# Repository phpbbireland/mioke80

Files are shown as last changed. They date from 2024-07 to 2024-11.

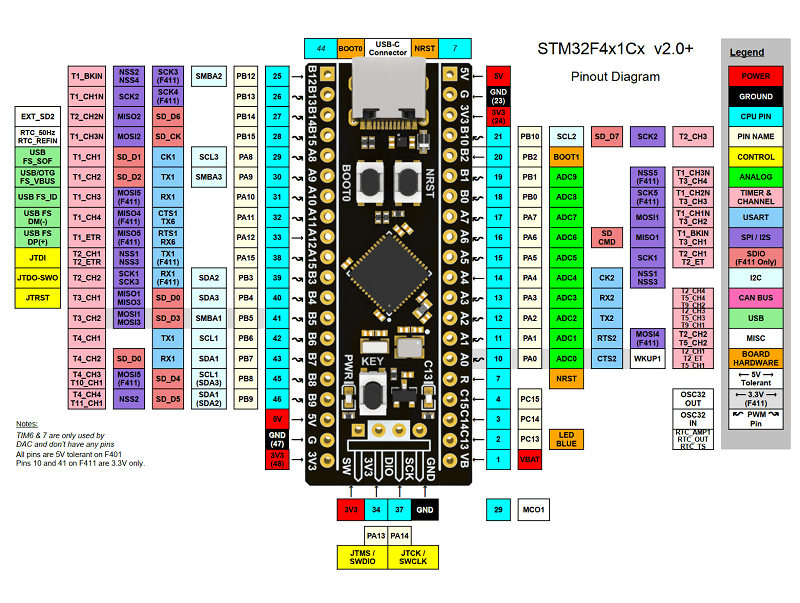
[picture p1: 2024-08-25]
blackpill_version/kicad/Pinout-Diagram.png

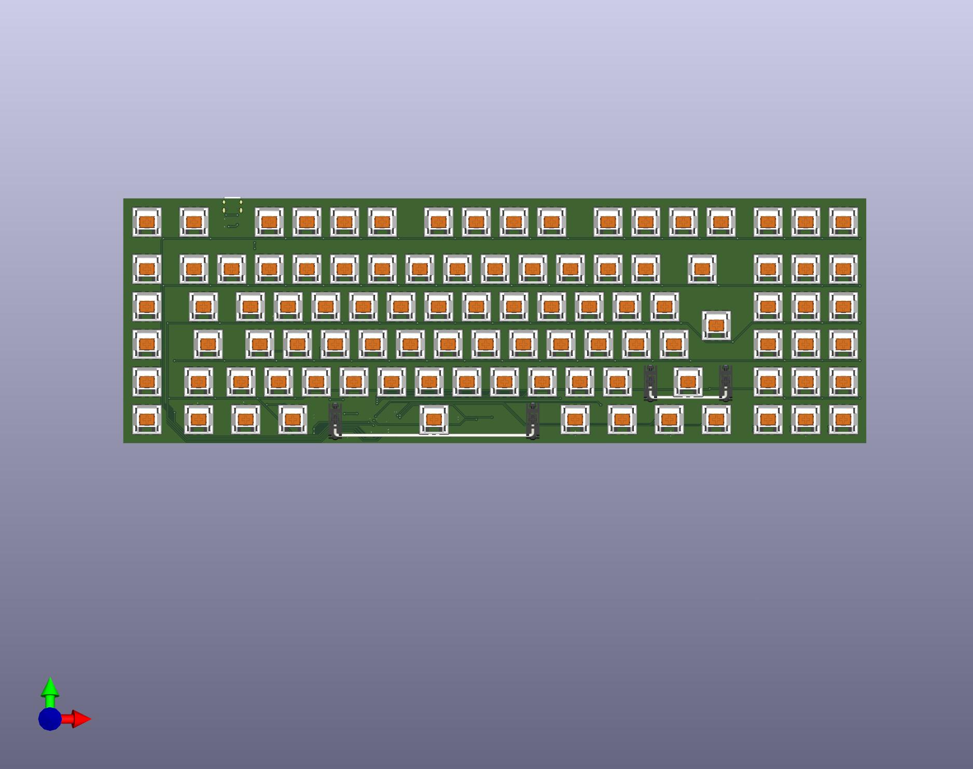
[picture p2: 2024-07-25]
images/Mioke80_front.jpg

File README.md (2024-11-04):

# Moving this repo to phpbbireland/mioke  
The new repo wil correct directory structure for this project... this repo will be deleted...

# mioke80 / ayla_411
QMK Based Open Hardware Keyboard with 99 Keys and Via Support

Just another open source / open hardware ~80% keyboard...

Ref: https://hackaday.io/project/197065-mioke80-iso-99-key-80-keyboard

+ Schematic complete...  
+ Software 80% complete...  
+ QMK/VIA code tested on Blackpill 411 Dev Board (see blackpill_version)... working 11th August 2024
+ Keyboard works... Now loads in usevia.app... Needed work to get RGB and Encoder working...

My main test code is now in /blackpill_version/QMK/ayla/ayla80  

I have designed a new test board using the STM32F411RETx, it contains all the necessary keyboard electronics (except for the key switches, matrix diodes and RGB leds as these are on
the actual keyboard PCB from the first prototype). Connection between boards is via 30 pin 1.27" pitch header connector.  

Note: *kicad2* folder contains working test copy, files will be moved to **kicad** once testing complete...  

Kicad Resources:  
[https://github.com/ebastler/marbastlib](https://github.com/ebastler/marbastlib)  
[https://github.com/joe-scotto/scottokeebs](https://github.com/joe-scotto/scottokeebs)

Matrix 10X10
```
    ┌───┐   ┌───┐┌───┐┌───┬───┬───┬───┐┌───┬───┬───┬───┐┌───┬───┬───┬───┐┌───┐┌───┐┌───┐
    │0,0│   │0,1││N/A││0,2│0,3│0,4│0,5││0,6│0,7│0,8│0,9││1,0│1,1│1,2│1,3││1,4││1,5││1,6│
    └───┘   └───┘└───┘└───┴───┴───┴───┘└───┴───┴───┴───┘└───┴───┴───┴───┘└───┘└───┘└───┘
    ┌───┐   ┌───┬───┬───┬───┬───┬───┬───┬───┬───┬───┬───┬───┬───┬───────┐┌───┐┌───┐┌───┐
    │1,7│   │1,8│1,9│2,0│2,1│2,2│2,3│2,4│2,5│2,6│2,7│2,8│2,9│3,0│  3,1  ││3,2││3,3││3,4│
    ├───┤   ├───┴─┬─┴─┬─┴─┬─┴─┬─┴─┬─┴─┬─┴─┬─┴─┬─┴─┬─┴─┬─┴─┬─┴─┬─┴─┬─────┤├───┤├───┤├───┤
    │3,5│   │ 3,6 │3,7│3,8│3,9│4,0│4,1│4,2│4,3│4,4│4,5│4,6│4,7│4,8│     ││4,9││5,0││5,1│
    ├───┤   ├─────┴┬──┴┬──┴┬──┴┬──┴┬──┴┬──┴┬──┴┬──┴┬──┴┬──┴┬──┴┬──┴┐    │├───┤├───┤├───┤
    │5,2│   │ 5,3  │5,4│5,5│5,6│5,7│5,8│5,9│6,0│6,1│6,2│6,3│6,4│6,5│6.6 ││6,7││6,8││6,9│
    ├───┤   ├────┬─┴─┬─┴─┬─┴─┬─┴─┬─┴─┬─┴─┬─┴─┬─┴─┬─┴─┬─┴─┬─┴─┬─┴───┴────┤├───┤├───┤├───┤
    │7,0│   │7,1 │7,2│7,3│7,4│7,5│7,6│7,7│7,8│7,9│8,0│8,1│8,2│    8,3   ││8,4││8,5││8,6│
    ├───┤   ├────┼───┴┬──┴─┬─┴───┴───┴───┴───┴───┴──┬┴───┼───┴┬────┬────┤├───┤├───┤├───┤
    │8,7│   │8.8 │8,9 │9,1 │           9,2          │9,3 │9,4 │9,5 │9,6 ││9,7││9,8││9,9│
    └───┘   └────┴────┴────┴────────────────────────┴────┴────┴────┴────┘└───┘└───┘└───┘
```

Will add 4x3 number keypad and rotary encoder which attaches via a 5x2 ribbon cable but might need more gpio pin, another process for this version?
The Blackpill version has an endoder... 
**Note**
Some GPIO pins may change as it appears some can't be used (according to sources)...

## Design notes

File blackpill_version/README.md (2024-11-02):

# mioke80 / ayla_411 / BlackPill Version

QMK Based Open Hardware Keyboard with 99 Keys + Rotary Encoder
Just another open source / open hardware ~80% keyboard...

Ref: https://hackaday.io/project/197065-mioke80-iso-99-key-80-keyboard

The new 10x10 matrix version requires only 20 GPIO pins, previously the 18x6 required 24. As it turns out, when taking into account pins that can't be used, and those, that are not recommended to use, we did not have enough GPIOs with old 19x6 matrix if we needed macros (flash), hence the 10x10 matrix update...

Schematic complete (10x10 matrix version)...  
Software 75% complete (no macros yet)...  

The original 18x6 matrix code was tested on Blackpill 411 Dev Board... working 11th August 2024  

The QMK folder for reference only, it's my local copy for building (not part of the main qmk_firmware repository).
Perhaps some day, if I get this complete...  

**Status**
+ Designed a prototype PCB using an STM32 411 Blackpill for testing... ***complete***
+ Test prototype PCB and initial keyboard code... ***complete, 100% working***
+ Now loads in usevia.app ***(I removed unnecessary files... RGB and Encoder require lots more work)***
+ Write and test RGB code... ***in progress***
+ I will proceed to a fully assembled PCB using the STM32F072CBT6 and associated components.

The keyboard code was simple enough but RGB code looks a little more involved...  
  
**Col/Row**
```
    ┌───┐   ┌───┐┌───┐┌───┬───┬───┬───┐┌───┬───┬───┬───┐┌───┬───┬───┬───┐┌───┐┌───┐┌───┐
    │0,0│   │0,1││N/A││0,2│0,3│0,4│0,5││0,6│0,7│0,8│0,9││1,0│1,1│1,2│1,3││1,4││1,5││1,6│
    └───┘   └───┘└───┘└───┴───┴───┴───┘└───┴───┴───┴───┘└───┴───┴───┴───┘└───┘└───┘└───┘
    ┌───┐   ┌───┬───┬───┬───┬───┬───┬───┬───┬───┬───┬───┬───┬───┬───────┐┌───┐┌───┐┌───┐
    │1,7│   │1,8│1,9│2,0│2,1│2,2│2,3│2,4│2,5│2,6│2,7│2,8│2,9│3,0│  3,1  ││3,2││3,3││3,4│
    ├───┤   ├───┴─┬─┴─┬─┴─┬─┴─┬─┴─┬─┴─┬─┴─┬─┴─┬─┴─┬─┴─┬─┴─┬─┴─┬─┴─┬─────┤├───┤├───┤├───┤
    │3,5│   │ 3,6 │3,7│3,8│3,9│4,0│4,1│4,2│4,3│4,4│4,5│4,6│4,7│4,8│     ││4,9││5,0││5,1│
    ├───┤   ├─────┴┬──┴┬──┴┬──┴┬──┴┬──┴┬──┴┬──┴┬──┴┬──┴┬──┴┬──┴┬──┴┐    │├───┤├───┤├───┤
    │5,2│   │ 5,3  │5,4│5,5│5,6│5,7│5,8│5,9│6,0│6,1│6,2│6,3│6,4│6,5│6.6 ││6,7││6,8││6,9│
    ├───┤   ├──────┴┬──┴┬──┴┬──┴┬──┴┬──┴┬──┴┬──┴┬──┴┬──┴┬──┴┬──┴┬──┴────┤├───┤├───┤├───┤
    │7,0│   │  7,1  │7,2│7,3│7,4│7,5│7,6│7,7│7,8│7,9│8,0│8,1│8,2│  8,3  ││8,4││8,5││8,6│
    ├───┤   ├────┬──┴─┬─┴──┬┴───┴───┴───┴───┴───┴───┴───┴┬──┴─┬─┴──┬────┤├───┤├───┤├───┤
    │8,7│   │8.8 │8,9 │9,1 │           9,2          │9,3 │9,4 │9,5 │9,6 ││9,7││9,8││9,9│
    └───┘   └────┴────┴────┴────────────────────────┴────┴────┴────┴────┘└───┘└───┘└───┘
```
**Matrix**
```
       C0    C1    C2    C3    C4    C5    C6    C7    C8    C9
      ┌───┐ ┌───┐ ┌───┐ ┌───┐ ┌───┐ ┌───┐ ┌───┐ ┌───┐ ┌───┐ ┌───┐
R0    │Rst│ │Esc│ │F1 │ │F2 │ │F3 │ │F4 │ │F5 │ │F6 │ │F7 │ │F8 │
      └───┘ └───┘ └───┘ └───┘ └───┘ └───┘ └───┘ └───┘ └───┘ └───┘
      ┌───┐ ┌───┐ ┌───┐ ┌───┐ ┌───┐ ┌───┐ ┌───┐ ┌───┐ ┌───┐ ┌───┐
R1    │F9 │ │F10│ │F11│ │F12│ │Prl│ │SL │ │Pse│ │M1 │ │ ` │ │ 1 │
      └───┘ └───┘ └───┘ └───┘ └───┘ └───┘ └───┘ └───┘ └───┘ └───┘
      ┌───┐ ┌───┐ ┌───┐ ┌───┐ ┌───┐ ┌───┐ ┌───┐ ┌───┐ ┌───┐ ┌───┐
R2    │ 2 │ │ 3 │ │ 4 │ │ 5 │ │ 6 │ │ 7 │ │ 8 │ │ 9 │ │ 0 │ │ - │
      └───┘ └───┘ └───┘ └───┘ └───┘ └───┘ └───┘ └───┘ └───┘ └───┘
      ┌───┐ ┌───┐ ┌───┐ ┌───┐ ┌───┐ ┌───┐ ┌───┐ ┌───┐ ┌───┐ ┌───┐
R3    │ + │ │BS │ │Ins│ │Hme│ │PgU│ │M2 │ │Tab│ │ Q │ │ W │ │ E │
      └───┘ └───┘ └───┘ └───┘ └───┘ └───┘ └───┘ └───┘ └───┘ └───┘
      ┌───┐ ┌───┐ ┌───┐ ┌───┐ ┌───┐ ┌───┐ ┌───┐ ┌───┐ ┌───┐ ┌───┐
R4    │ R │ │ T │ │ Y │ │ U │ │ I │ │ O │ │ P │ │ [ │ │ ] │ │ # │
      └───┘ └───┘ └───┘ └───┘ └───┘ └───┘ └───┘ └───┘ └───┘ └───┘
      ┌───┐ ┌───┐ ┌───┐ ┌───┐ ┌───┐ ┌───┐ ┌───┐ ┌───┐ ┌───┐ ┌───┐
R5    │Del│ │End│ │PgD│ │M3 │ │Cap│ │ A │ │ S │ │ D │ │ F │ │ G │
      └───┘ └───┘ └───┘ └───┘ └───┘ └───┘ └───┘ └───┘ └───┘ └───┘
      ┌───┐ ┌───┐ ┌───┐ ┌───┐ ┌───┐ ┌───┐ ┌───┐ ┌───┐ ┌───┐ ┌───┐
R6    │ H │ │ J │ │ K │ │ L │ │ ; │ │ @ │ │C R│ │<< │ │ > │ │ >>│
      └───┘ └───┘ └───┘ └───┘ └───┘ └───┘ └───┘ └───┘ └───┘ └───┘
      ┌───┐ ┌───┐ ┌───┐ ┌───┐ ┌───┐ ┌───┐ ┌───┐ ┌───┐ ┌───┐ ┌───┐
R7    │M4 │ │LSh│ │ Z │ │ X │ │ C │ │ V │ │ B │ │ N │ │ M │ │ , │
      └───┘ └───┘ └───┘ └───┘ └───┘ └───┘ └───┘ └───┘ └───┘ └───┘
      ┌───┐ ┌───┐ ┌───┐ ┌───┐ ┌───┐ ┌───┐ ┌───┐ ┌───┐ ┌───┐ ┌───┐
R8    │ . │ │ / │ │ \ │ │Rsh│ │M5 │ │ ↑ │ │M6 │ │M7 │ │Lcr│ │GUI│
      └───┘ └───┘ └───┘ └───┘ └───┘ └───┘ └───┘ └───┘ └───┘ └───┘
      ┌───┐ ┌───┐ ┌───┐ ┌───┐ ┌───┐ ┌───┐ ┌───┐ ┌───┐ ┌───┐ ┌───┐
R9    │Llt│ │S P│ │Rlt│ │Fn │ │Men│ │Rcr│ │ ← │ │ ↓ │ │ → │ │SPA│
      └───┘ └───┘ └───┘ └───┘ └───┘ └───┘ └───┘ └───┘ └───┘ └───┘
```

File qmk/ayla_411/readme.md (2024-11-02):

# ayla_411

ayla_411

*A short description of the keyboard/project*

* Keyboard Maintainer: [Mike](https://github.com/phpbbireland)
* Hardware Supported: *The PCBs, controllers supported*
* Hardware Availability: *Links to where you can find this hardware*

Make example for this keyboard (after setting up your build environment):

    make ayla_411:default
    make ayla/ayla80:via

Flashing example for this keyboard:

    make ayla_411:default:flash ?
    qmk flash ayla_ayla80_via.bin -km via

See the [build environment setup](https://docs.qmk.fm/#/getting_started_build_tools) and the [make instructions](https://docs.qmk.fm/#/getting_started_make_guide) for more information. Brand new to QMK? Start with our [Complete Newbs Guide](https://docs.qmk.fm/#/newbs).

## Bootloader

Enter the bootloader in 3 ways:

* **Bootmagic reset**: Hold down the key at (0,0) in the matrix (usually the top left key or Escape) and plug in the keyboard
* **Physical reset button**: Briefly press the button on the back of the PCB - some may have pads you must short instead
* **Keycode in layout**: Press the key mapped to `QK_BOOT` if it is available

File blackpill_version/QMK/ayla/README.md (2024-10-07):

# ayla keyboards

ayla

*A short description of the keyboard/project*

* Keyboard Maintainer: [Mike](https://github.com/phpbbireland)
* Hardware Supported: [Hackaday](https://hackaday.io/project/197065-mioke80-iso-ansi-99-key-80-keyboard)
* Hardware Availability: *Once complete and 100% working, I will supply Links to where you can find this hardware*

This keyboard is similar to others in QMK keyboard directory, except it includes dedicated Marco keys and optional rotary encoder for volume etc...
I have not attempted to add it to QMK, I am not familiar with the process, perhaps later...

Make example for this keyboard (after setting up your build environment):

    example: make ayla_ayla80:via

Flashing example for this keyboard:

    example: make ayla_ayla80:via:flash or ./flash.sh ayla_ayla80_via.bin

See the [build environment setup](https://docs.qmk.fm/#/getting_started_build_tools) and the [make instructions](https://docs.qmk.fm/#/getting_started_make_guide) for more information. Brand new to QMK? Start with our [Complete Newbs Guide](https://docs.qmk.fm/#/newbs).

## Bootloader

Enter the bootloader in 3 ways: Note fully implemented yet

* **Bootmagic reset**: Hold down the key at (0,0) in the matrix (usually the top left key or Escape) and plug in the keyboard
* **Physical reset button**: Briefly press the button on the back of the PCB - some may have pads you must short instead
* **Keycode in layout**: Press the key mapped to `QK_BOOT` if it is available

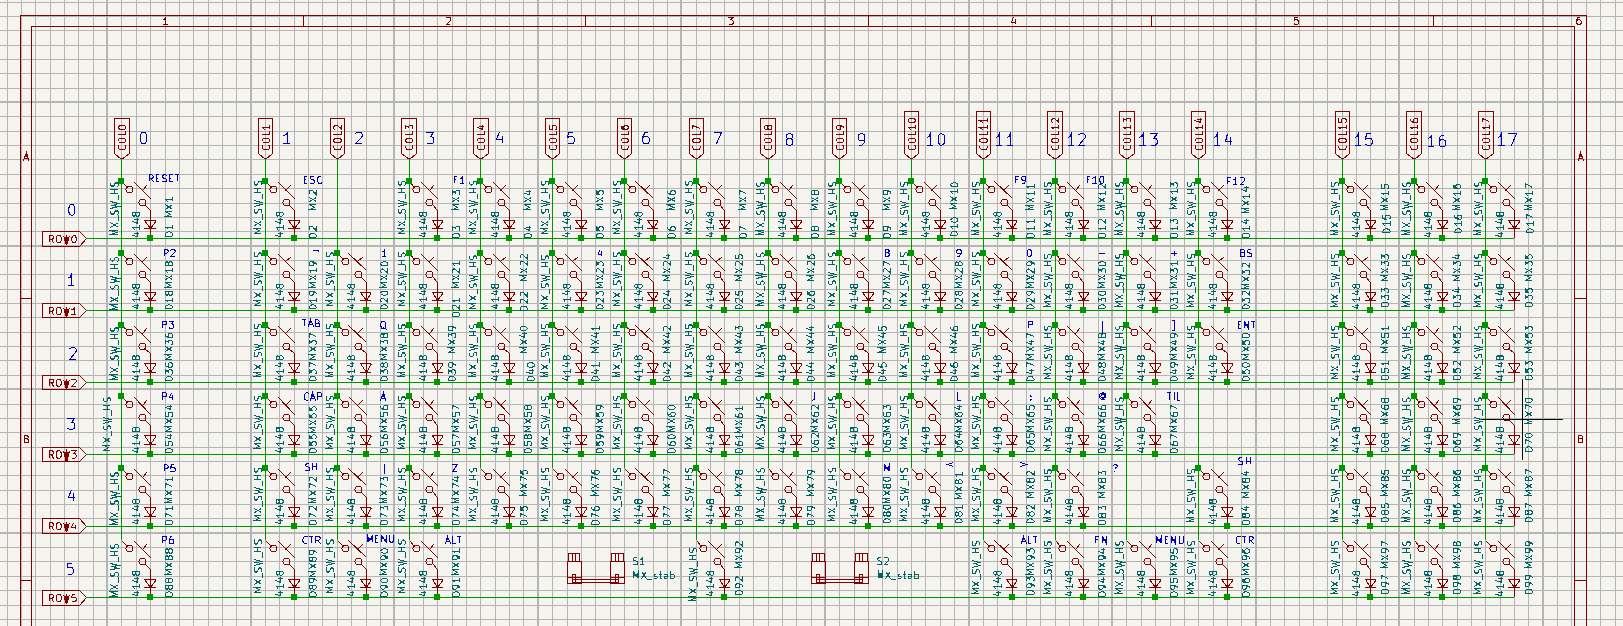
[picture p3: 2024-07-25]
images/schematic_image_keys.png

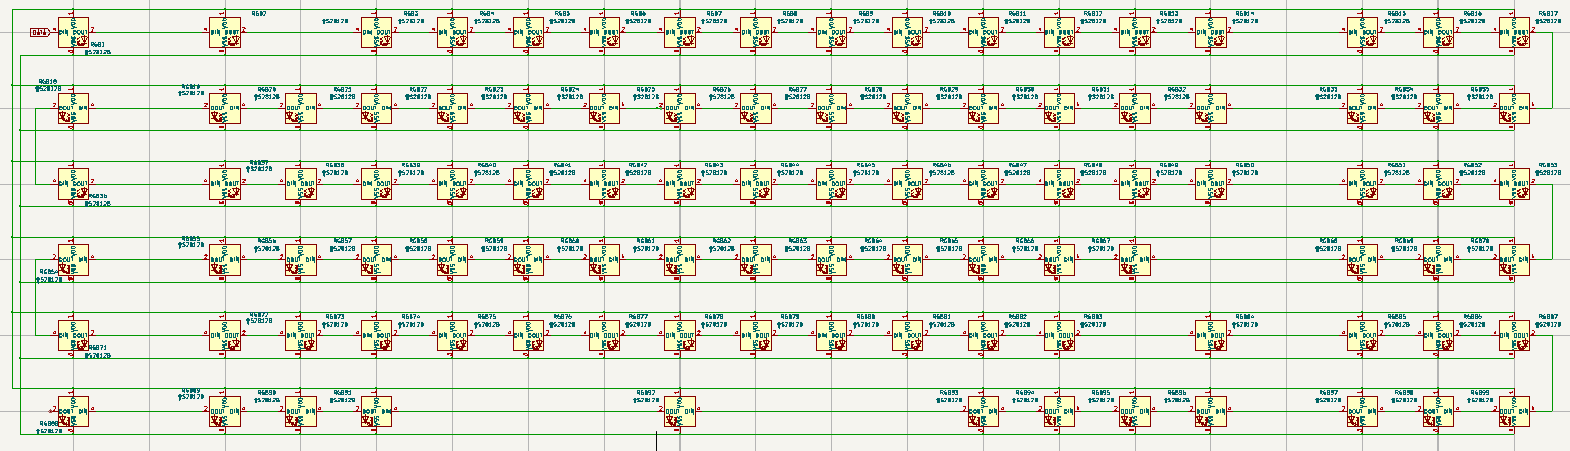
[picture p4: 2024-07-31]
images/schematic_rgb.png

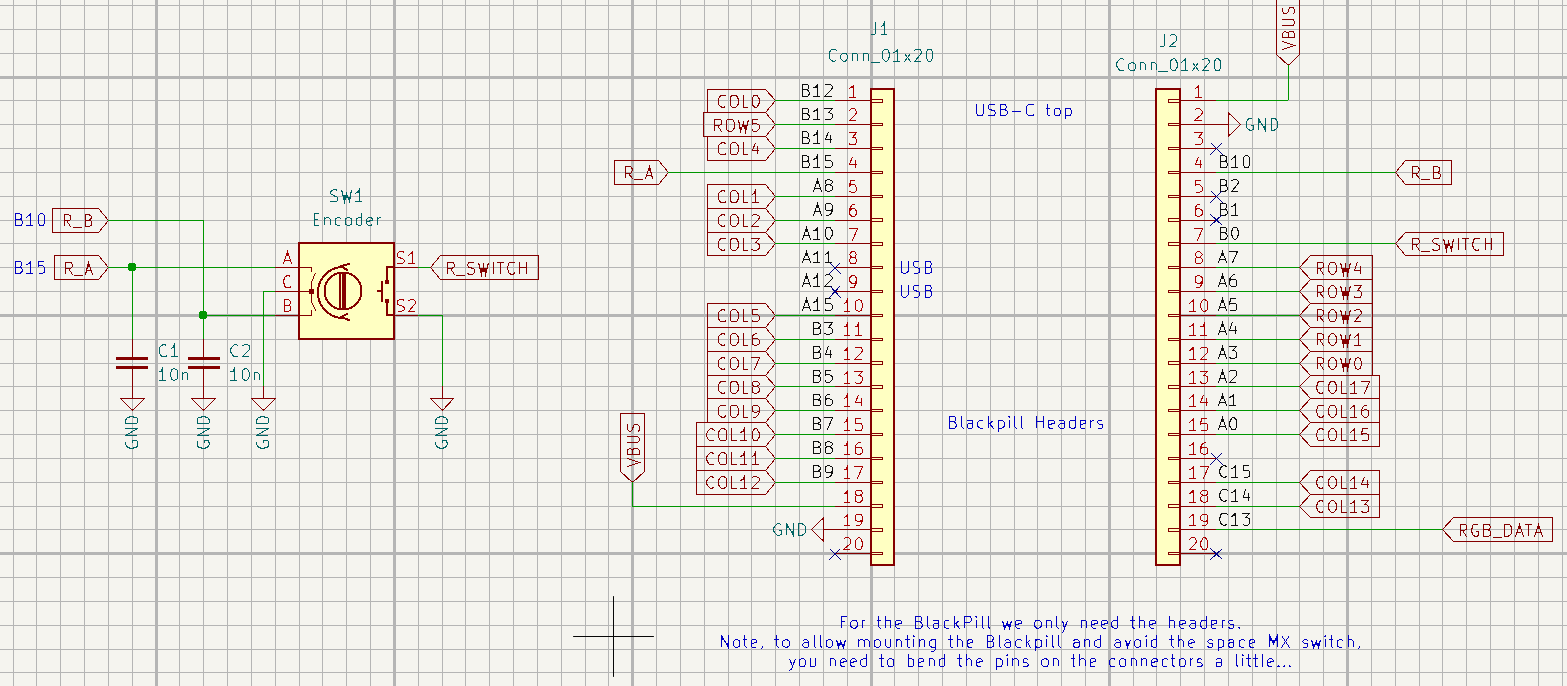
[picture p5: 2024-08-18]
blackpill_version/images/blackpill_schematic.png

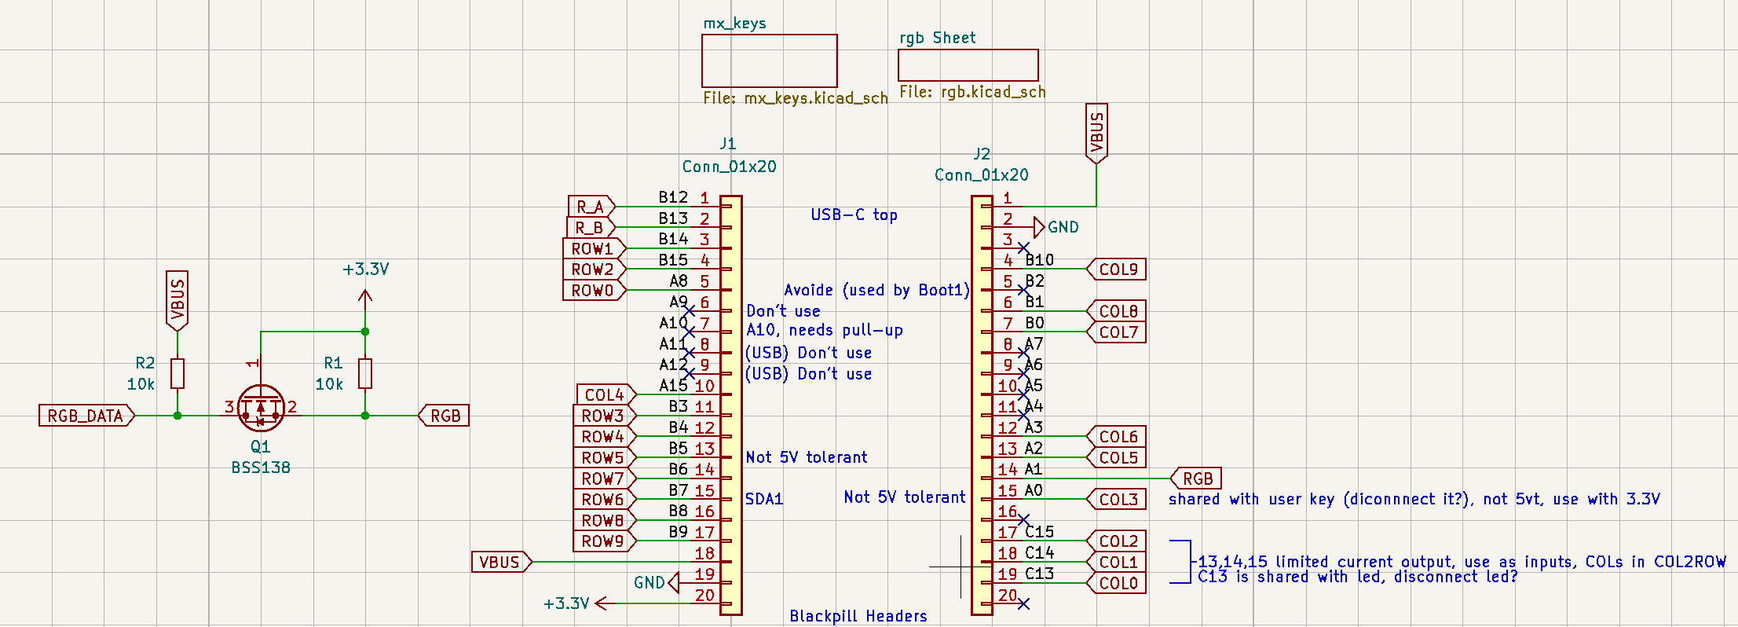
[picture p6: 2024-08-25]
blackpill_version/images/schematic_411.png

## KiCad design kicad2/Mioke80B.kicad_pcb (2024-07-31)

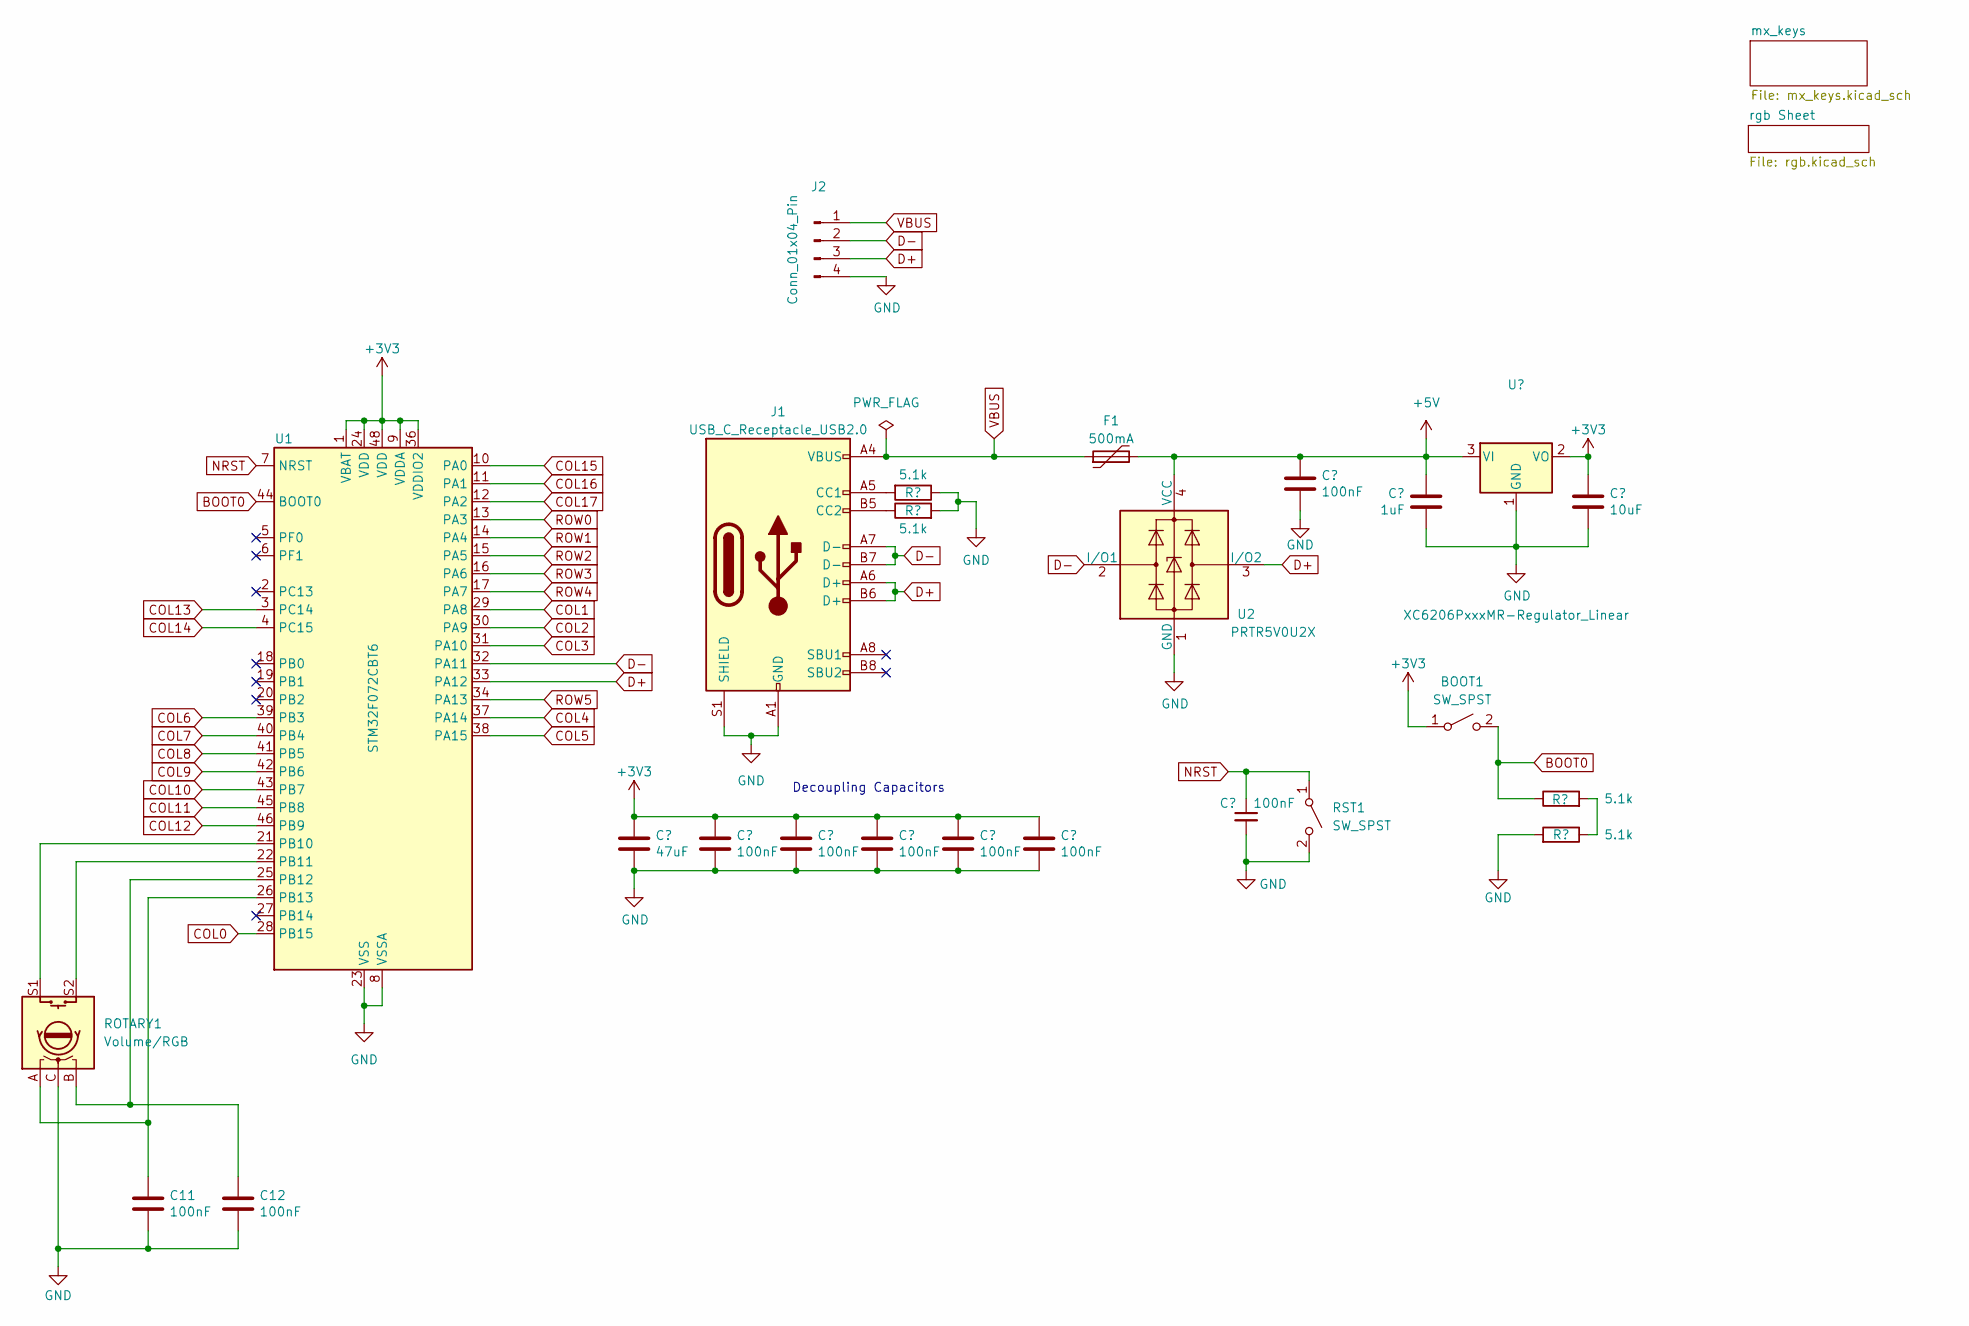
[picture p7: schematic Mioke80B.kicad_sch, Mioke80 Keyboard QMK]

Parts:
BOOT1: SW_SPST; SW_SPST_TL3342
C1, C3, C4, C5, C6, C7, C8, C11, C12: 100nF; C_0402_1005Metric; LCSC C307331
C2: 47uF; C_0805_2012Metric; LCSC C307331
C9: 1uF; C_0402_1005Metric; LCSC C307331
C10: 10uF; C_0805_2012Metric; LCSC C307331
F1: 500mA; Fuse_1206_3216Metric; LCSC C135341
J1: USB_C_Receptacle_USB2.0; USB_C_Receptacle_HRO_TYPE-C-31-M-12; JlcRotOffset 180
J2: Conn_01x04_Pin; JST_EH_B4B-EH-A_1x04_P2.50mm_Vertical
R1, R2, R3, R4: 5.1k; R_0402_1005Metric
ROTARY1: Volume/RGB; RotaryEncoder_Alps_EC11E-Switch_Vertical_H20mm
RST1: SW_SPST; SW_SPST_TL3342
U1: STM32F072CBT6; LQFP-48_7x7mm_P0.5mm; JlcRotOffset 90
U2: PRTR5V0U2X; SOT-143; LCSC C2827688
U3: XC6206PxxxMR-Regulator_Linear; SOT-23; LCSC C5446

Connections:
+3V3: BOOT1.1 (A), C2.1, C3.1, C4.1, C5.1, C6.1, C7.1, C10.1, U1.1 (VBAT), U1.9 (VDDA), U1.24 (VDD), U1.36 (VDDIO2), U1.48 (VDD), U3.2 (VO)
+5V: C8.1, C9.1, F1.2, U2.4 (VCC), U3.3 (VI)
BOOT0: BOOT1.2 (B), R3.1, U1.44 (BOOT0)
COL0: U1.28 (PB15); also elsewhere on the board
COL1: U1.29 (PA8); also elsewhere on the board
COL2: U1.30 (PA9); also elsewhere on the board
COL3: U1.31 (PA10); also elsewhere on the board
COL4: U1.37 (PA14); also elsewhere on the board
COL5: U1.38 (PA15); also elsewhere on the board
COL6: U1.39 (PB3); also elsewhere on the board
COL7: U1.40 (PB4); also elsewhere on the board
COL8: U1.41 (PB5); also elsewhere on the board
COL9: U1.42 (PB6); also elsewhere on the board
COL10: U1.43 (PB7); also elsewhere on the board
COL11: U1.45 (PB8); also elsewhere on the board
COL12: U1.46 (PB9); also elsewhere on the board
COL13: U1.3 (PC14); also elsewhere on the board
COL14: U1.4 (PC15); also elsewhere on the board
COL15: U1.10 (PA0); also elsewhere on the board
COL16: U1.11 (PA1); also elsewhere on the board
COL17: U1.12 (PA2); also elsewhere on the board
D+: J1.A6 (D+), J1.B6 (D+), J2.3, U1.33 (PA12), U2.3 (I/O2); also elsewhere on the board
D-: J2.2, U1.32 (PA11), U2.2 (I/O1)
GND: C1.2, C2.2, C3.2, C4.2, C5.2, C6.2, C7.2, C8.2, C9.2, C10.2, C11.2, C12.2, J2.4, R1.1, R2.2, R4.2, ROTARY1.C, RST1.2 (B), U1.8 (VSSA), U1.23 (VSS), U1.35 (VSS), U1.47 (VSS), U2.1 (GND), U3.1 (GND)
NRST: C1.1, RST1.1 (A), U1.7 (NRST)
unnamed: J1.A5 (CC1), R1.2
unnamed: J1.B5 (CC2), R2.1
unnamed: R3.2, R4.1
unnamed: ROTARY1.S1, U1.21 (PB10)
unnamed: ROTARY1.S2, U1.22 (PB11)
unnamed: C12.1, ROTARY1.B, U1.25 (PB12)
unnamed: C11.1, ROTARY1.A, U1.26 (PB13)
ROW0: U1.13 (PA3); also elsewhere on the board
ROW1: U1.14 (PA4); also elsewhere on the board
ROW2: U1.15 (PA5); also elsewhere on the board
ROW3: U1.16 (PA6); also elsewhere on the board
ROW4: U1.17 (PA7); also elsewhere on the board
ROW5: U1.34 (PA13); also elsewhere on the board
VBUS: F1.1, J1.A4 (VBUS), J1.A9 (VBUS), J1.B4 (VBUS), J1.B9 (VBUS), J2.1

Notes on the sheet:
Decoupling Capacitors

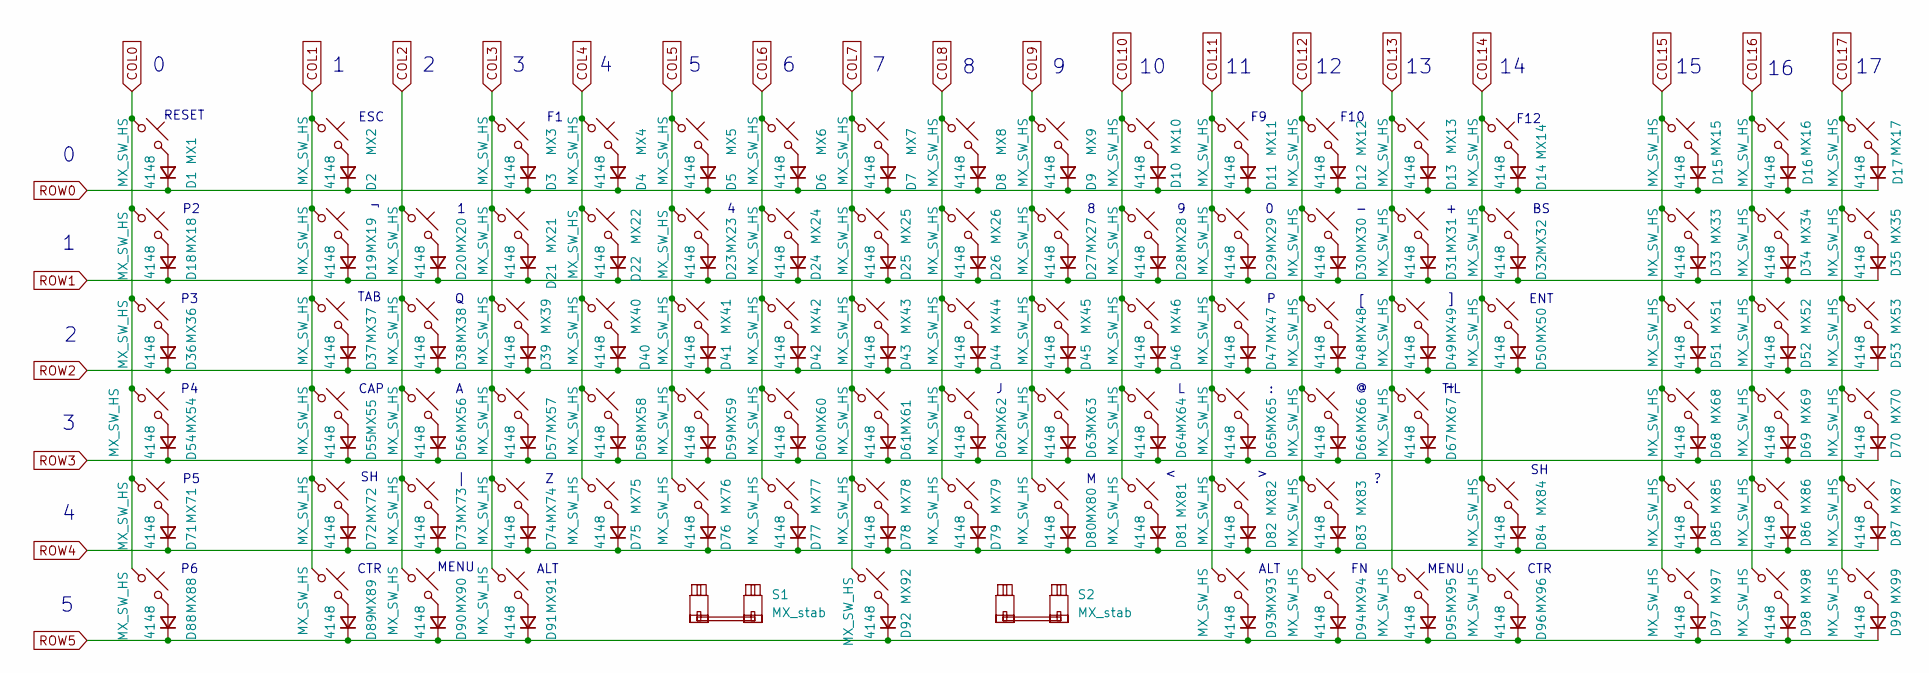
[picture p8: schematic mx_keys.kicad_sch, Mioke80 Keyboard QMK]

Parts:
D1, D2, D3, D4, D5, D6, D7, D8, D9, D10, D11, D12, D13, D14, D15, D16, D17, D18, D19, D20, D21, D22, D23, D24, D25, D26, D27, D28, D29, D30, D31, D32, D33, D34, D35, D36, D37, D38, D39, D40, D41, D42, D43, D44, D45, D46, D47, D48, D49, D50, D51, D52, D53, D54, D55, D56, D57, D58, D59, D60, D61, D62, D63, D64, D65, D66, D67, D68, D69, D70, D71, D72, D73, D74, D75, D76, D77, D78, D79, D80, D81, D82, D83, D84, D85, D86, D87, D88, D89, D90, D91, D92, D93, D94, D95, D96, D97, D98, D99: 4148; Diode_SOD-123
MX1, MX2, MX3, MX4, MX5, MX6, MX7, MX8, MX9, MX10, MX11, MX12, MX13, MX14, MX15, MX16, MX17, MX18, MX19, MX20, MX21, MX22, MX23, MX24, MX25, MX26, MX27, MX28, MX29, MX30, MX31, MX32, MX33, MX34, MX35, MX36, MX38, MX39, MX40, MX41, MX42, MX43, MX44, MX45, MX46, MX47, MX48, MX49, MX50, MX51, MX52, MX53, MX54, MX56, MX57, MX58, MX59, MX60, MX61, MX62, MX63, MX65, MX66, MX67, MX68, MX69, MX70, MX71, MX73, MX74, MX76, MX77, MX79, MX80, MX82, MX83, MX85, MX86, MX87, MX88, MX92, MX97, MX98, MX99: MX_SW_HS; SW_MX_HS_CPG151101S11_1u
MX37: MX_SW_HS; SW_MX_HS_CPG151101S11_1.5u
MX55, MX64: MX_SW_HS; SW_MX_HS_CPG151101S11_1.75u
MX72, MX89, MX90, MX91, MX93, MX94, MX95, MX96: MX_SW_HS; SW_MX_HS_CPG151101S11_1.25u
MX75, MX78, MX81: MX_SW_HS; SW_MX_HS_1U
MX84: MX_SW_HS; SW_MX_HS_2.75U
S1: MX_stab; Stabilizer_MX_6.25u
S2: MX_stab; Stabilizer_MX_3.00u

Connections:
COL0: MX1.1, MX18.1, MX36.1, MX54.1, MX71.1, MX88.1; also elsewhere on the board
COL1: MX2.1, MX19.1, MX37.1, MX55.1, MX72.1, MX89.1; also elsewhere on the board
COL2: MX20.1, MX38.1, MX56.1, MX73.1, MX90.1; also elsewhere on the board
COL3: MX3.1, MX21.1, MX39.1, MX57.1, MX74.1, MX91.1; also elsewhere on the board
COL4: MX4.1, MX22.1, MX40.1, MX58.1, MX75.1; also elsewhere on the board
COL5: MX5.1, MX23.1, MX41.1, MX59.1, MX76.1; also elsewhere on the board
COL6: MX6.1, MX24.1, MX42.1, MX60.1, MX77.1; also elsewhere on the board
COL7: MX7.1, MX25.1, MX43.1, MX61.1, MX78.1, MX92.1; also elsewhere on the board
COL8: MX8.1, MX26.1, MX44.1, MX62.1, MX79.1; also elsewhere on the board
COL9: MX9.1, MX27.1, MX45.1, MX63.1, MX80.1; also elsewhere on the board
COL10: MX10.1, MX28.1, MX46.1, MX64.1, MX81.1; also elsewhere on the board
COL11: MX11.1, MX29.1, MX47.1, MX65.1, MX82.1, MX93.1; also elsewhere on the board
COL12: MX12.1, MX30.1, MX48.1, MX66.1, MX83.1, MX94.1; also elsewhere on the board
COL13: MX13.1, MX31.1, MX49.1, MX67.1, MX95.1; also elsewhere on the board
COL14: MX14.1, MX32.1, MX50.1, MX84.1, MX96.1; also elsewhere on the board
COL15: MX15.1, MX33.1, MX51.1, MX68.1, MX85.1, MX97.1; also elsewhere on the board
COL16: MX16.1, MX34.1, MX52.1, MX69.1, MX86.1, MX98.1; also elsewhere on the board
COL17: MX17.1, MX35.1, MX53.1, MX70.1, MX87.1, MX99.1; also elsewhere on the board
unnamed: D1.2 (A), MX1.2
unnamed: D2.2 (A), MX2.2
unnamed: D3.2 (A), MX3.2
unnamed: D4.2 (A), MX4.2
unnamed: D5.2 (A), MX5.2
unnamed: D6.2 (A), MX6.2
unnamed: D7.2 (A), MX7.2
unnamed: D8.2 (A), MX8.2
unnamed: D9.2 (A), MX9.2
unnamed: D10.2 (A), MX10.2
unnamed: D11.2 (A), MX11.2
unnamed: D12.2 (A), MX12.2
unnamed: D13.2 (A), MX13.2
unnamed: D14.2 (A), MX14.2
unnamed: D15.2 (A), MX15.2
unnamed: D16.2 (A), MX16.2
unnamed: D17.2 (A), MX17.2
unnamed: D18.2 (A), MX18.2
unnamed: D19.2 (A), MX19.2
unnamed: D20.2 (A), MX20.2
unnamed: D21.2 (A), MX21.2
unnamed: D22.2 (A), MX22.2
unnamed: D23.2 (A), MX23.2
unnamed: D24.2 (A), MX24.2
unnamed: D25.2 (A), MX25.2
unnamed: D26.2 (A), MX26.2
unnamed: D27.2 (A), MX27.2
unnamed: D28.2 (A), MX28.2
unnamed: D29.2 (A), MX29.2
unnamed: D30.2 (A), MX30.2
unnamed: D31.2 (A), MX31.2
unnamed: D32.2 (A), MX32.2
unnamed: D33.2 (A), MX33.2
unnamed: D34.2 (A), MX34.2
unnamed: D35.2 (A), MX35.2
unnamed: D36.2 (A), MX36.2
unnamed: D37.2 (A), MX37.2
unnamed: D38.2 (A), MX38.2
unnamed: D39.2 (A), MX39.2
unnamed: D40.2 (A), MX40.2
unnamed: D41.2 (A), MX41.2
unnamed: D42.2 (A), MX42.2
unnamed: D43.2 (A), MX43.2
unnamed: D44.2 (A), MX44.2
unnamed: D45.2 (A), MX45.2
unnamed: D46.2 (A), MX46.2
unnamed: D47.2 (A), MX47.2
unnamed: D48.2 (A), MX48.2
unnamed: D49.2 (A), MX49.2
unnamed: D50.2 (A), MX50.2
unnamed: D51.2 (A), MX51.2
unnamed: D52.2 (A), MX52.2
unnamed: D53.2 (A), MX53.2
unnamed: D54.2 (A), MX54.2
unnamed: D55.2 (A), MX55.2
unnamed: D56.2 (A), MX56.2
unnamed: D57.2 (A), MX57.2
unnamed: D58.2 (A), MX58.2
unnamed: D59.2 (A), MX59.2
unnamed: D60.2 (A), MX60.2
unnamed: D61.2 (A), MX61.2
unnamed: D62.2 (A), MX62.2
unnamed: D63.2 (A), MX63.2
unnamed: D64.2 (A), MX64.2
unnamed: D65.2 (A), MX65.2
unnamed: D66.2 (A), MX66.2
unnamed: D67.2 (A), MX67.2
unnamed: D68.2 (A), MX68.2
unnamed: D69.2 (A), MX69.2
unnamed: D70.2 (A), MX70.2
unnamed: D71.2 (A), MX71.2
unnamed: D72.2 (A), MX72.2
unnamed: D73.2 (A), MX73.2
unnamed: D74.2 (A), MX74.2
unnamed: D75.2 (A), MX75.2
unnamed: D76.2 (A), MX76.2
unnamed: D77.2 (A), MX77.2
unnamed: D78.2 (A), MX78.2
unnamed: D79.2 (A), MX79.2
unnamed: D80.2 (A), MX80.2
unnamed: D81.2 (A), MX81.2
unnamed: D82.2 (A), MX82.2
unnamed: D83.2 (A), MX83.2
unnamed: D84.2 (A), MX84.2
unnamed: D85.2 (A), MX85.2
unnamed: D86.2 (A), MX86.2
unnamed: D87.2 (A), MX87.2
unnamed: D88.2 (A), MX88.2
unnamed: D89.2 (A), MX89.2
unnamed: D90.2 (A), MX90.2
unnamed: D91.2 (A), MX91.2
unnamed: D92.2 (A), MX92.2
unnamed: D93.2 (A), MX93.2
unnamed: D94.2 (A), MX94.2
unnamed: D95.2 (A), MX95.2
unnamed: D96.2 (A), MX96.2
unnamed: D97.2 (A), MX97.2
unnamed: D98.2 (A), MX98.2
unnamed: D99.2 (A), MX99.2
ROW0: D1.1 (K), D2.1 (K), D3.1 (K), D4.1 (K), D5.1 (K), D6.1 (K), D7.1 (K), D8.1 (K), D9.1 (K), D10.1 (K), D11.1 (K), D12.1 (K), D13.1 (K), D14.1 (K), D15.1 (K), D16.1 (K), D17.1 (K); also elsewhere on the board
ROW1: D18.1 (K), D19.1 (K), D20.1 (K), D21.1 (K), D22.1 (K), D23.1 (K), D24.1 (K), D25.1 (K), D26.1 (K), D27.1 (K), D28.1 (K), D29.1 (K), D30.1 (K), D31.1 (K), D32.1 (K), D33.1 (K), D34.1 (K), D35.1 (K); also elsewhere on the board
ROW2: D36.1 (K), D37.1 (K), D38.1 (K), D39.1 (K), D40.1 (K), D41.1 (K), D42.1 (K), D43.1 (K), D44.1 (K), D45.1 (K), D46.1 (K), D47.1 (K), D48.1 (K), D49.1 (K), D50.1 (K), D51.1 (K), D52.1 (K), D53.1 (K); also elsewhere on the board
ROW3: D54.1 (K), D55.1 (K), D56.1 (K), D57.1 (K), D58.1 (K), D59.1 (K), D60.1 (K), D61.1 (K), D62.1 (K), D63.1 (K), D64.1 (K), D65.1 (K), D66.1 (K), D67.1 (K), D68.1 (K), D69.1 (K), D70.1 (K); also elsewhere on the board
ROW4: D71.1 (K), D72.1 (K), D73.1 (K), D74.1 (K), D75.1 (K), D76.1 (K), D77.1 (K), D78.1 (K), D79.1 (K), D80.1 (K), D81.1 (K), D82.1 (K), D83.1 (K), D84.1 (K), D85.1 (K), D86.1 (K), D87.1 (K); also elsewhere on the board
ROW5: D88.1 (K), D89.1 (K), D90.1 (K), D91.1 (K), D92.1 (K), D93.1 (K), D94.1 (K), D95.1 (K), D96.1 (K), D97.1 (K), D98.1 (K), D99.1 (K); also elsewhere on the board

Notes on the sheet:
TAB
ALT
F12
F10
RESET
CTR
CAP
ENT
TIL
4 5
ESC
MENU

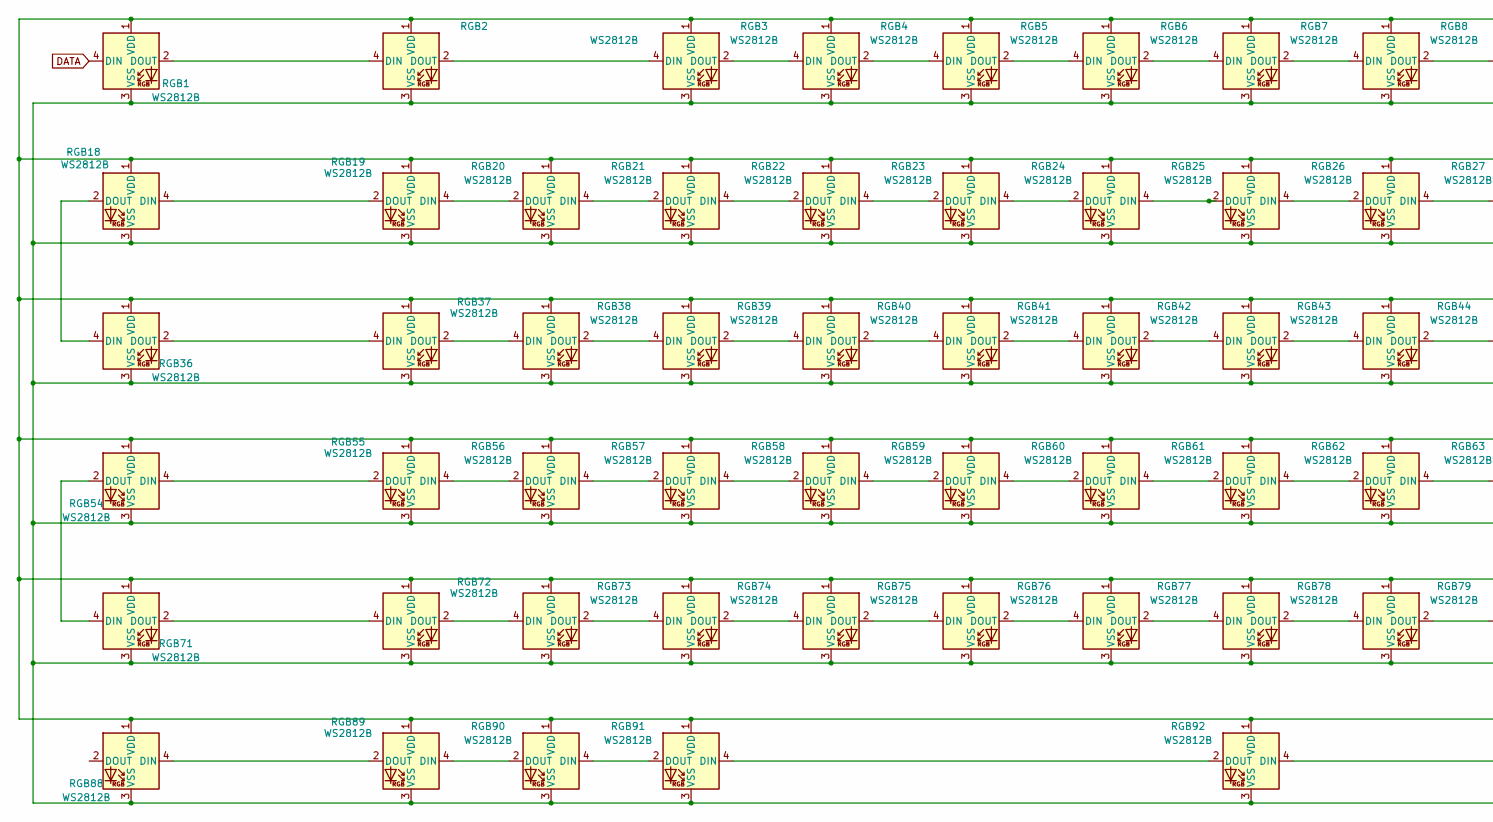
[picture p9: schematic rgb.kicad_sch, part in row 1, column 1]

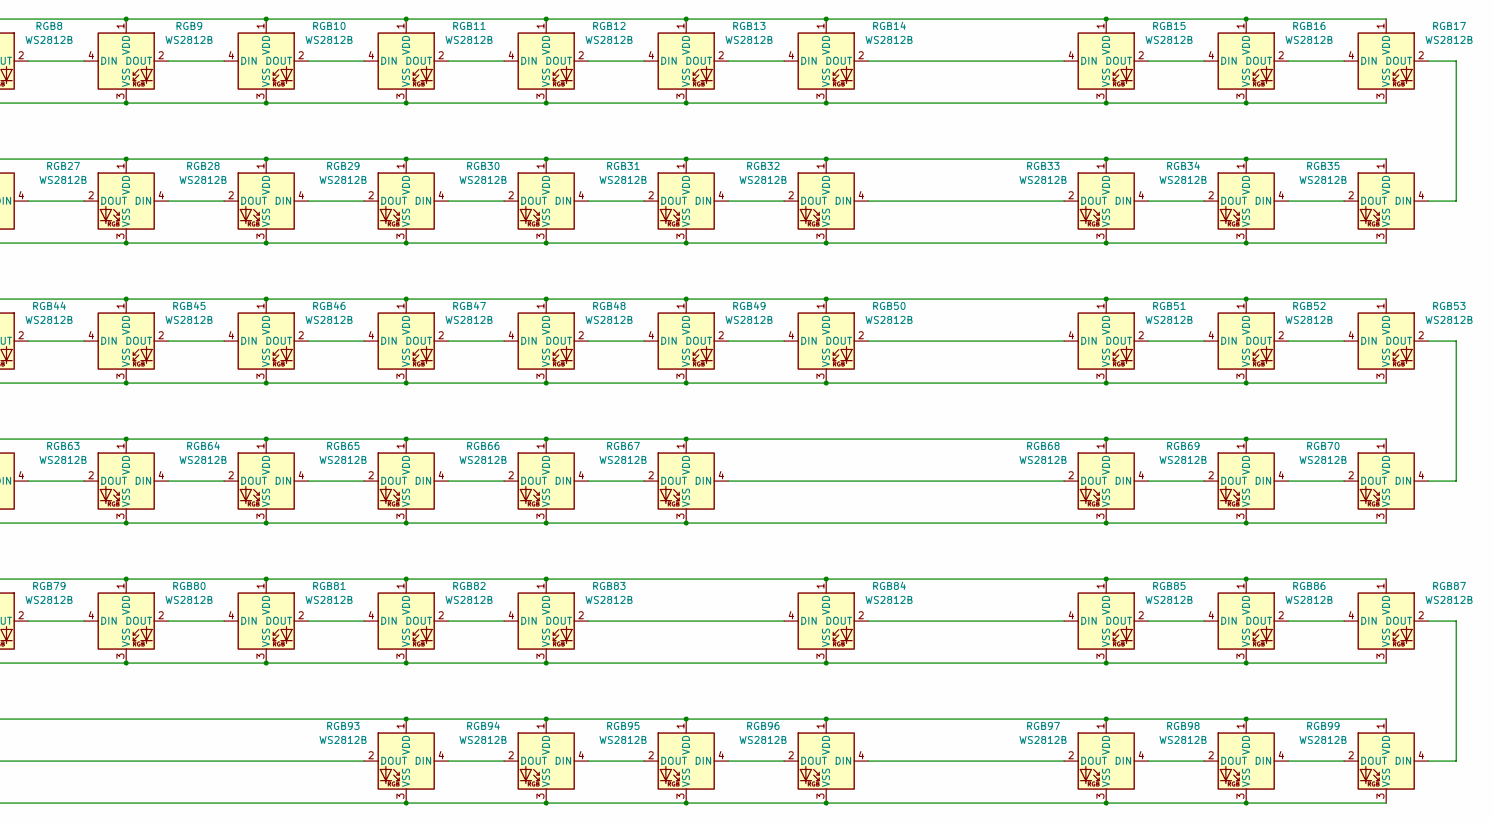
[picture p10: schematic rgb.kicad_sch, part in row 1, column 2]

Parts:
RGB1, RGB2, RGB3, RGB4, RGB5, RGB6, RGB7, RGB8, RGB9, RGB10, RGB11, RGB12, RGB13, RGB14, RGB15, RGB16, RGB17, RGB18, RGB19, RGB20, RGB21, RGB22, RGB23, RGB24, RGB25, RGB26, RGB27, RGB28, RGB29, RGB30, RGB31, RGB32, RGB33, RGB34, RGB35, RGB36, RGB37, RGB38, RGB39, RGB40, RGB41, RGB42, RGB43, RGB44, RGB45, RGB46, RGB47, RGB48, RGB49, RGB50, RGB51, RGB52, RGB53, RGB54, RGB55, RGB56, RGB57, RGB58, RGB59, RGB60, RGB61, RGB62, RGB63, RGB64, RGB65, RGB66, RGB67, RGB68, RGB69, RGB70, RGB71, RGB72, RGB73, RGB74, RGB75, RGB76, RGB77, RGB78, RGB79, RGB80, RGB81, RGB82, RGB83, RGB84, RGB85, RGB86, RGB87, RGB88, RGB89, RGB90, RGB91, RGB92, RGB93, RGB94, RGB95, RGB96, RGB97, RGB98, RGB99: WS2812B; LED_WS2812B-2020_PLCC4_2.0x2.0mm

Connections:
DATA: RGB1.4 (DIN)
unnamed: RGB1.2 (DOUT), RGB2.4 (DIN)
unnamed: RGB1.1 (VDD), RGB2.1 (VDD), RGB3.1 (VDD), RGB4.1 (VDD), RGB5.1 (VDD), RGB6.1 (VDD), RGB7.1 (VDD), RGB8.1 (VDD), RGB9.1 (VDD), RGB10.1 (VDD), RGB11.1 (VDD), RGB12.1 (VDD), RGB13.1 (VDD), RGB14.1 (VDD), RGB15.1 (VDD), RGB16.1 (VDD), RGB17.1 (VDD), RGB18.1 (VDD), RGB19.1 (VDD), RGB20.1 (VDD), RGB21.1 (VDD), RGB22.1 (VDD), RGB23.1 (VDD), RGB24.1 (VDD), RGB25.1 (VDD), RGB26.1 (VDD), RGB27.1 (VDD), RGB28.1 (VDD), RGB29.1 (VDD), RGB30.1 (VDD), RGB31.1 (VDD), RGB32.1 (VDD), RGB33.1 (VDD), RGB34.1 (VDD), RGB35.1 (VDD), RGB36.1 (VDD), RGB37.1 (VDD), RGB38.1 (VDD), RGB39.1 (VDD), RGB40.1 (VDD), RGB41.1 (VDD), RGB42.1 (VDD), RGB43.1 (VDD), RGB44.1 (VDD), RGB45.1 (VDD), RGB46.1 (VDD), RGB47.1 (VDD), RGB48.1 (VDD), RGB49.1 (VDD), RGB50.1 (VDD), RGB51.1 (VDD), RGB52.1 (VDD), RGB53.1 (VDD), RGB54.1 (VDD), RGB55.1 (VDD), RGB56.1 (VDD), RGB57.1 (VDD), RGB58.1 (VDD), RGB59.1 (VDD), RGB60.1 (VDD), RGB61.1 (VDD), RGB62.1 (VDD), RGB63.1 (VDD), RGB64.1 (VDD), RGB65.1 (VDD), RGB66.1 (VDD), RGB67.1 (VDD), RGB68.1 (VDD), RGB69.1 (VDD), RGB70.1 (VDD), RGB71.1 (VDD), RGB72.1 (VDD), RGB73.1 (VDD), RGB74.1 (VDD), RGB75.1 (VDD), RGB76.1 (VDD), RGB77.1 (VDD), RGB78.1 (VDD), RGB79.1 (VDD), RGB80.1 (VDD), RGB81.1 (VDD), RGB82.1 (VDD), RGB83.1 (VDD), RGB84.1 (VDD), RGB85.1 (VDD), RGB86.1 (VDD), RGB87.1 (VDD), RGB88.1 (VDD), RGB89.1 (VDD), RGB90.1 (VDD), RGB91.1 (VDD), RGB92.1 (VDD), RGB93.1 (VDD), RGB94.1 (VDD), RGB95.1 (VDD), RGB96.1 (VDD), RGB97.1 (VDD), RGB98.1 (VDD), RGB99.1 (VDD)
unnamed: RGB1.3 (VSS), RGB2.3 (VSS), RGB3.3 (VSS), RGB4.3 (VSS), RGB5.3 (VSS), RGB6.3 (VSS), RGB7.3 (VSS), RGB8.3 (VSS), RGB9.3 (VSS), RGB10.3 (VSS), RGB11.3 (VSS), RGB12.3 (VSS), RGB13.3 (VSS), RGB14.3 (VSS), RGB15.3 (VSS), RGB16.3 (VSS), RGB17.3 (VSS), RGB18.3 (VSS), RGB19.3 (VSS), RGB20.3 (VSS), RGB21.3 (VSS), RGB22.3 (VSS), RGB23.3 (VSS), RGB24.3 (VSS), RGB25.3 (VSS), RGB26.3 (VSS), RGB27.3 (VSS), RGB28.3 (VSS), RGB29.3 (VSS), RGB30.3 (VSS), RGB31.3 (VSS), RGB32.3 (VSS), RGB33.3 (VSS), RGB34.3 (VSS), RGB35.3 (VSS), RGB36.3 (VSS), RGB37.3 (VSS), RGB38.3 (VSS), RGB39.3 (VSS), RGB40.3 (VSS), RGB41.3 (VSS), RGB42.3 (VSS), RGB43.3 (VSS), RGB44.3 (VSS), RGB45.3 (VSS), RGB46.3 (VSS), RGB47.3 (VSS), RGB48.3 (VSS), RGB49.3 (VSS), RGB50.3 (VSS), RGB51.3 (VSS), RGB52.3 (VSS), RGB53.3 (VSS), RGB54.3 (VSS), RGB55.3 (VSS), RGB56.3 (VSS), RGB57.3 (VSS), RGB58.3 (VSS), RGB59.3 (VSS), RGB60.3 (VSS), RGB61.3 (VSS), RGB62.3 (VSS), RGB63.3 (VSS), RGB64.3 (VSS), RGB65.3 (VSS), RGB66.3 (VSS), RGB67.3 (VSS), RGB68.3 (VSS), RGB69.3 (VSS), RGB70.3 (VSS), RGB71.3 (VSS), RGB72.3 (VSS), RGB73.3 (VSS), RGB74.3 (VSS), RGB75.3 (VSS), RGB76.3 (VSS), RGB77.3 (VSS), RGB78.3 (VSS), RGB79.3 (VSS), RGB80.3 (VSS), RGB81.3 (VSS), RGB82.3 (VSS), RGB83.3 (VSS), RGB84.3 (VSS), RGB85.3 (VSS), RGB86.3 (VSS), RGB87.3 (VSS), RGB88.3 (VSS), RGB89.3 (VSS), RGB90.3 (VSS), RGB91.3 (VSS), RGB92.3 (VSS), RGB93.3 (VSS), RGB94.3 (VSS), RGB95.3 (VSS), RGB96.3 (VSS), RGB97.3 (VSS), RGB98.3 (VSS), RGB99.3 (VSS)
unnamed: RGB2.2 (DOUT), RGB3.4 (DIN)
unnamed: RGB3.2 (DOUT), RGB4.4 (DIN)
unnamed: RGB4.2 (DOUT), RGB5.4 (DIN)
unnamed: RGB5.2 (DOUT), RGB6.4 (DIN)
unnamed: RGB6.2 (DOUT), RGB7.4 (DIN)
unnamed: RGB7.2 (DOUT), RGB8.4 (DIN)
unnamed: RGB8.2 (DOUT), RGB9.4 (DIN)
unnamed: RGB9.2 (DOUT), RGB10.4 (DIN)
unnamed: RGB10.2 (DOUT), RGB11.4 (DIN)
unnamed: RGB11.2 (DOUT), RGB12.4 (DIN)
unnamed: RGB12.2 (DOUT), RGB13.4 (DIN)
unnamed: RGB13.2 (DOUT), RGB14.4 (DIN)
unnamed: RGB14.2 (DOUT), RGB15.4 (DIN)
unnamed: RGB15.2 (DOUT), RGB16.4 (DIN)
unnamed: RGB16.2 (DOUT), RGB17.4 (DIN)
unnamed: RGB17.2 (DOUT), RGB35.4 (DIN)
unnamed: RGB18.4 (DIN), RGB19.2 (DOUT)
unnamed: RGB18.2 (DOUT), RGB36.4 (DIN)
unnamed: RGB19.4 (DIN), RGB20.2 (DOUT)
unnamed: RGB20.4 (DIN), RGB21.2 (DOUT)
unnamed: RGB21.4 (DIN), RGB22.2 (DOUT)
unnamed: RGB22.4 (DIN), RGB23.2 (DOUT)
unnamed: RGB23.4 (DIN), RGB24.2 (DOUT)
unnamed: RGB24.4 (DIN), RGB25.2 (DOUT)
unnamed: RGB25.4 (DIN), RGB26.2 (DOUT)
unnamed: RGB26.4 (DIN), RGB27.2 (DOUT)
unnamed: RGB27.4 (DIN), RGB28.2 (DOUT)
unnamed: RGB28.4 (DIN), RGB29.2 (DOUT)
unnamed: RGB29.4 (DIN), RGB30.2 (DOUT)
unnamed: RGB30.4 (DIN), RGB31.2 (DOUT)
unnamed: RGB31.4 (DIN), RGB32.2 (DOUT)
unnamed: RGB32.4 (DIN), RGB33.2 (DOUT)
unnamed: RGB33.4 (DIN), RGB34.2 (DOUT)
unnamed: RGB34.4 (DIN), RGB35.2 (DOUT)
unnamed: RGB36.2 (DOUT), RGB37.4 (DIN)
unnamed: RGB37.2 (DOUT), RGB38.4 (DIN)
unnamed: RGB38.2 (DOUT), RGB39.4 (DIN)
unnamed: RGB39.2 (DOUT), RGB40.4 (DIN)
unnamed: RGB40.2 (DOUT), RGB41.4 (DIN)
unnamed: RGB41.2 (DOUT), RGB42.4 (DIN)
unnamed: RGB42.2 (DOUT), RGB43.4 (DIN)
unnamed: RGB43.2 (DOUT), RGB44.4 (DIN)
unnamed: RGB44.2 (DOUT), RGB45.4 (DIN)
unnamed: RGB45.2 (DOUT), RGB46.4 (DIN)
unnamed: RGB46.2 (DOUT), RGB47.4 (DIN)
unnamed: RGB47.2 (DOUT), RGB48.4 (DIN)
unnamed: RGB48.2 (DOUT), RGB49.4 (DIN)
unnamed: RGB49.2 (DOUT), RGB50.4 (DIN)
unnamed: RGB50.2 (DOUT), RGB51.4 (DIN)
unnamed: RGB51.2 (DOUT), RGB52.4 (DIN)
unnamed: RGB52.2 (DOUT), RGB53.4 (DIN)
unnamed: RGB53.2 (DOUT), RGB70.4 (DIN)
unnamed: RGB54.4 (DIN), RGB55.2 (DOUT)
unnamed: RGB54.2 (DOUT), RGB71.4 (DIN)
unnamed: RGB55.4 (DIN), RGB56.2 (DOUT)
unnamed: RGB56.4 (DIN), RGB57.2 (DOUT)
unnamed: RGB57.4 (DIN), RGB58.2 (DOUT)
unnamed: RGB58.4 (DIN), RGB59.2 (DOUT)
unnamed: RGB59.4 (DIN), RGB60.2 (DOUT)
unnamed: RGB60.4 (DIN), RGB61.2 (DOUT)
unnamed: RGB61.4 (DIN), RGB62.2 (DOUT)
unnamed: RGB62.4 (DIN), RGB63.2 (DOUT)
unnamed: RGB63.4 (DIN), RGB64.2 (DOUT)
unnamed: RGB64.4 (DIN), RGB65.2 (DOUT)
unnamed: RGB65.4 (DIN), RGB66.2 (DOUT)
unnamed: RGB66.4 (DIN), RGB67.2 (DOUT)
unnamed: RGB67.4 (DIN), RGB68.2 (DOUT)
unnamed: RGB68.4 (DIN), RGB69.2 (DOUT)
unnamed: RGB69.4 (DIN), RGB70.2 (DOUT)
unnamed: RGB71.2 (DOUT), RGB72.4 (DIN)
unnamed: RGB72.2 (DOUT), RGB73.4 (DIN)
unnamed: RGB73.2 (DOUT), RGB74.4 (DIN)
unnamed: RGB74.2 (DOUT), RGB75.4 (DIN)
unnamed: RGB75.2 (DOUT), RGB76.4 (DIN)
unnamed: RGB76.2 (DOUT), RGB77.4 (DIN)
unnamed: RGB77.2 (DOUT), RGB78.4 (DIN)
unnamed: RGB78.2 (DOUT), RGB79.4 (DIN)
unnamed: RGB79.2 (DOUT), RGB80.4 (DIN)
unnamed: RGB80.2 (DOUT), RGB81.4 (DIN)
unnamed: RGB81.2 (DOUT), RGB82.4 (DIN)
unnamed: RGB82.2 (DOUT), RGB83.4 (DIN)
unnamed: RGB83.2 (DOUT), RGB84.4 (DIN)
unnamed: RGB84.2 (DOUT), RGB85.4 (DIN)
unnamed: RGB85.2 (DOUT), RGB86.4 (DIN)
unnamed: RGB86.2 (DOUT), RGB87.4 (DIN)
unnamed: RGB87.2 (DOUT), RGB99.4 (DIN)
unnamed: RGB88.4 (DIN), RGB89.2 (DOUT)
unnamed: RGB89.4 (DIN), RGB90.2 (DOUT)
unnamed: RGB90.4 (DIN), RGB91.2 (DOUT)
unnamed: RGB91.4 (DIN), RGB92.2 (DOUT)
unnamed: RGB92.4 (DIN), RGB93.2 (DOUT)
unnamed: RGB93.4 (DIN), RGB94.2 (DOUT)
unnamed: RGB94.4 (DIN), RGB95.2 (DOUT)
unnamed: RGB95.4 (DIN), RGB96.2 (DOUT)
unnamed: RGB96.4 (DIN), RGB97.2 (DOUT)
unnamed: RGB97.4 (DIN), RGB98.2 (DOUT)
unnamed: RGB98.4 (DIN), RGB99.2 (DOUT)

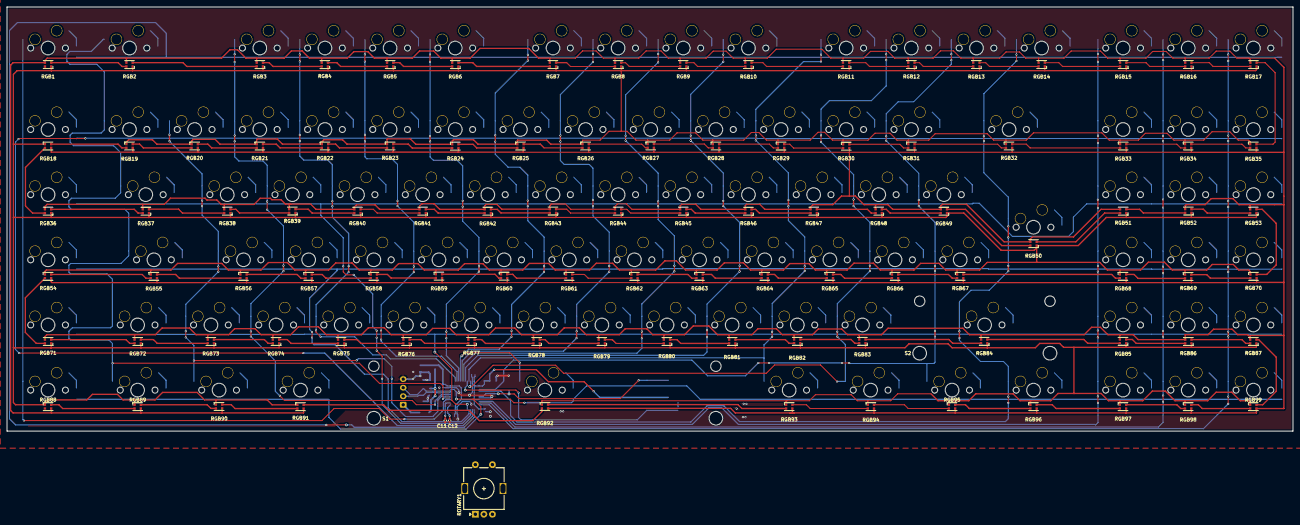
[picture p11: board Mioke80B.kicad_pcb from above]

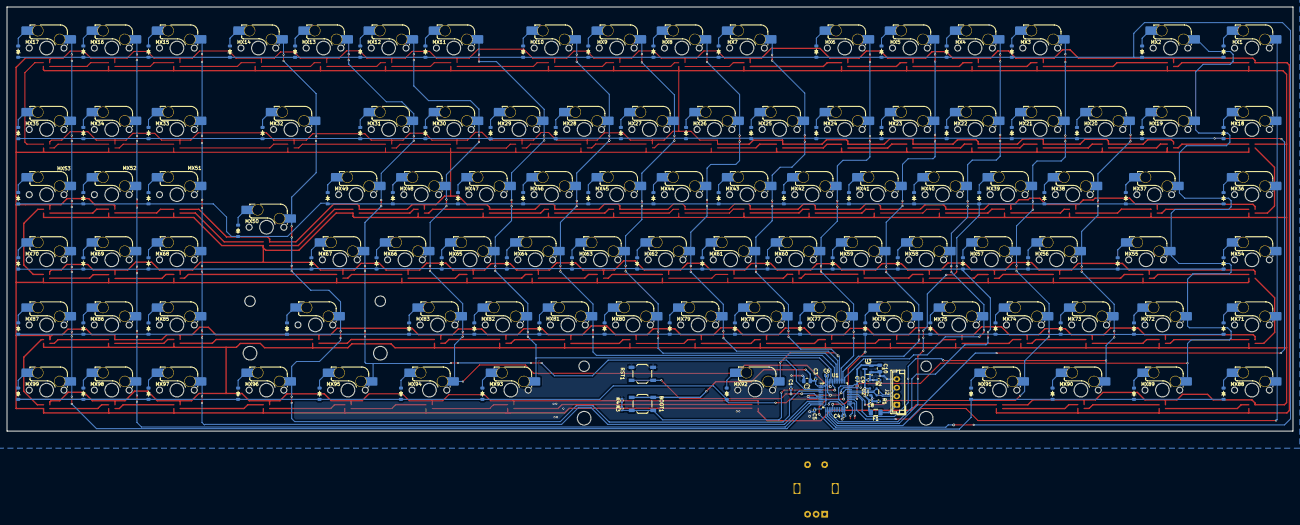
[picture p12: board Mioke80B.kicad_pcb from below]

Board: 2 copper layers, 376.0 x 124.0 mm, 323 parts (219 on the bottom side), 236 nets.

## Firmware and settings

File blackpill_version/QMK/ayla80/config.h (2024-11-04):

/* Copyright (C) 2022 jonylee@hfd
 *
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
 * You should have received a copy of the GNU General Public License
 * along with this program.  If not, see <http://www.gnu.org/licenses/>.
 */

#pragma once

//#include <ws2812.h>

#define USB_POLLING_INTERVAL_MS 1
#define WAIT_FOR_USB

#define MATRIX_ROWS 10
#define MATRIX_COLS 10


/*
#define RGB_TRIGGER_ON_KEYDOWN

#define WS2812_DI_PIN A1



#define WS2812_LED_COUNT 99
#define WS2812_TIMING	1250
#define WS2812_T1H	900
#define WS2812_T0H	350
#define WS2812_TRST_US	280
#define WS2812_RGBW true                             // Enables RGBW support (except i2c driver)
#define WS2812_BYTE_ORDER WS2812_BYTE_ORDER_RGB      // WS2812B-2020

*/

/*
#define RGBLIGHT_LED_COUNT 99
#define RGBLIGHT_HUE_STEP	8
#define RGBLIGHT_SAT_STEP	17
#define RGBLIGHT_VAL_STEP	17
#define RGBLIGHT_LIMIT_VAL	255
#define RGBLIGHT_SLEEP true
#define RGBLIGHT_MAX_LAYERS 4

*/
// compiled ok 30/09/2024


/*
	https://docs.qmk.fm/drivers/eeprom

	SPI Driver Configuration
	Currently QMK supports 25xx-series chips over SPI. As such, requires a working spi_master driver configuration.
	You can override the driver configuration via your config.h:

#define SPI_DRIVER                           SPID1
#define SPI_SCK_PIN                          A5
#define SPI_SCK_PAL_MODE                     5
#define SPI_MOSI_PIN                         A7
#define SPI_MOSI_PAL_MODE                    5
#define SPI_MISO_PIN                         A6
#define SPI_MISO_PAL_MODE                    5

#define EXTERNAL_EEPROM_SPI_SLAVE_SELECT_PIN A4
#define EXTERNAL_EEPROM_SPI_CLOCK_DIVISOR    64

#define STM32_ONBOARD_EEPROM_SIZE
#define EXTERNAL_EEPROM_BYTE_COUNT           8192
#define EXTERNAL_EEPROM_PAGE_SIZE	         32
#define EXTERNAL_EEPROM_ADDRESS_SIZE	     2


*/

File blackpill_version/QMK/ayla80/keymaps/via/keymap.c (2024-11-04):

// Copyright 2023 QMK
// SPDX-License-Identifier: GPL-2.0-or-later
// see keyboard.info
//#include "kb.h"

// File: ayla/ayla80/keymaps/via/keymap.c

#include QMK_KEYBOARD_H

enum layer_names {
    _BASE,
    _FN,
    _ME,
    _SP
};


enum custom_keycodes
{
    P1, P2, P3  // store a few sample passwords
};

const uint16_t PROGMEM keymaps[][MATRIX_ROWS][MATRIX_COLS] = {

    // Fix: #1 swapped  KC_ENT,   KC_TILDE (now KC_NUHS), worked for first pcb (temp until new pcb, then revert KCC_ENT, KC_TILDE)
    // Replace KC_TILDE with KC_NUHS for ascii (non us) keep for new pcb...
    // #1 for next discrete board

    // use this for new discrete pcb, else fix 1 above to compile for blackpill first board

    /*
    [_BASE] = LAYOUT_411_iso(
                KC_TRNS, KC_ESC,  KC_F1,   KC_F2,   KC_F3,   KC_F4,    KC_F5,  KC_F6,   KC_F7,   KC_F8,   KC_F9,   KC_F10,  KC_F11,  KC_F12,  KC_PSCR, KC_SCRL,   KC_PAUSE,
                KC_TRNS, KC_GRV,  KC_1,    KC_2,    KC_3,    KC_4,     KC_5,   KC_6,    KC_7,    KC_8,    KC_9,    KC_0,    KC_MINS, KC_EQL,  KC_BSPC, KC_INSERT, KC_HOME,
                KC_PGUP, KC_TRNS, KC_TAB,  KC_Q,    KC_W,    KC_E,     KC_R,   KC_T,    KC_Y,    KC_U,    KC_I,    KC_O,    KC_P,    KC_LBRC, KC_RBRC, KC_DEL,    KC_END,
                KC_PGDN, KC_TRNS, KC_CAPS, KC_A,    KC_S,    KC_D,     KC_F,   KC_G,    KC_H,    KC_J,    KC_K,    KC_L,    KC_SCLN, KC_QUOT, KC_NUHS, KC_ENT,    KC_TRNS,
                KC_TRNS, KC_TRNS, KC_TRNS, KC_LSFT, KC_Z,     KC_X,   KC_C,    KC_V,    KC_B,    KC_N,    KC_M,    KC_COMM, KC_DOT,  KC_SLSH, KC_BSLS, KC_RSFT,   KC_TRNS,
                KC_UP,   KC_TRNS, KC_TRNS, KC_LCTL, KC_LGUI, KC_LALT,  KC_SPC, KC_RALT, MO(_FN), KC_MENU, KC_RCTL, KC_LEFT, KC_DOWN, KC_RIGHT
                ),
    [_FN]   = LAYOUT_411(
                QK_BOOT, _______, _______, _______, _______, _______, _______, _______, _______, _______, _______, _______, _______, _______, RGB_TOG, RGB_HUI,   RGB_HUD,
                _______, _______, P1,      P2,      P3,      _______, _______, _______, _______, _______, _______, _______, _______, _______, _______, _______,   _______,
                _______, _______, _______, _______, _______, _______, _______, _______, _______, _______, _______, _______, _______, _______, _______, _______,   RGB_VAI,
                _______, _______, _______, _______, _______, _______, _______, _______, _______, _______, _______, _______, _______, _______, _______, _______,   _______,
                _______, _______, _______, _______, _______, _______, _______, _______, _______, _______, _______, _______, _______, _______, _______, _______,   _______,
                _______, _______, _______, _______, _______, _______, _______, _______, _______, _______, _______, RGB_SPD, RGB_VAD, RGB_SPI
            ),

    */

    /* Arranged in 10x10 matrix (MATRIX_ROWS 10, MATRIX_COLS 10) as this reduces the GPIO requirements from 23 to 20 pins)

       Note for ISO layout, the forward slash has moved to right side beside back slash (KC_SLSH, KC_BSLS, KC_RSFT), this allows for a larger left shift...
       see https://github.com/phpbbireland/mioke80/blob/main/blackpill_version/images/ayla80v2.png
       For ANSI layout, this may/will change...

       * LAYOUT name i.e. "LAYOUT_411_iso" should match in keyboard.json file * KC_ENT KC_BSLS
    */

    /*  Row:    0        1        2          3        4        5        6         7        8         9       */
    [_BASE] = LAYOUT_411_iso(
                KC_TRNS, KC_ESC,  KC_F1,     KC_F2,   KC_F3,   KC_F4,   KC_F5,    KC_F6,   KC_F7,    KC_F8,
                KC_F9,   KC_F10,  KC_F11,    KC_F12,  KC_PSCR, KC_SCRL, KC_PAUSE, KC_TRNS, KC_GRV,   KC_1,
                KC_2,    KC_3,    KC_4,      KC_5,    KC_6,    KC_7,    KC_8,     KC_9,    KC_0,     KC_MINS,
                KC_EQL,  KC_BSPC, KC_INSERT, KC_HOME, KC_PGUP, KC_TRNS, KC_TAB,   KC_Q,    KC_W,     KC_E,
                KC_R,    KC_T,    KC_Y,      KC_U,    KC_I,    KC_O,    KC_P,     KC_LBRC, KC_RBRC,  KC_DEL,
                KC_END,  KC_PGDN, KC_TRNS,   KC_CAPS, KC_A,    KC_S,    KC_D,     KC_F,    KC_G,     KC_H,
                KC_J,    KC_K,    KC_L,      KC_SCLN, KC_QUOT, KC_NUHS, KC_TRNS,  KC_ENT,  KC_TRNS,  KC_TRNS,
                KC_TRNS, KC_LSFT, KC_BSLS,   KC_Z,    KC_X,    KC_C,    KC_V,     KC_B,    KC_N,     KC_M,
                KC_COMM, KC_DOT,  KC_SLSH,   KC_RSFT, KC_TRNS, KC_UP,   KC_TRNS,  KC_TRNS, KC_LCTL,  KC_LGUI,
                KC_LALT, KC_SPC,  KC_RALT,   MO(_FN), KC_MENU, KC_RCTL, KC_LEFT,  KC_DOWN, KC_RIGHT, KC_TRNS
            ),

    [_FN]   = LAYOUT_411_iso(
                _______, _______, _______, _______, _______, _______, _______, _______, _______, _______, _______, _______, _______, _______, _______, RGB_TOG, RGB_HUI, RGB_HUD,
                _______, _______, _______, _______, _______, _______, _______, _______, _______, _______, _______, _______, _______, _______, _______, _______, _______, _______,
                _______, _______, _______, _______, _______, _______, _______, _______, _______, _______, _______, _______, _______, _______, _______, RGB_VAI, _______, _______,
                _______, _______, _______, _______, _______, _______, _______, _______, _______, _______, _______, _______, _______, _______,          _______, _______, _______,
                _______, _______, _______, _______, _______, _______, _______, _______, _______, _______, _______, _______, _______, _______,          _______, _______, _______,
                _______, _______, _______, _______,                            _______,                            _______, _______, _______, _______, RGB_SPD, RGB_VAD, RGB_SPI
            ),
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

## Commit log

2024-07-25 Kicad Files...
    [Mioke80.kicad_sch, mx_keys.kicad_sch]
2024-07-27 working active version
    [Mioke80.kicad_sch, mx_keys.kicad_sch, rgb.kicad_sch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]
2024-07-31 new files
    [Mioke80B.kicad_pcb, Mioke80B.kicad_sch]
2024-08-15 Add files via upload
    Image of edited marbastlib-mx:SW_MX_HS_CPG151101S11_xxx to include graphics to align the RGB led ...
2024-08-18 Added blackpill board image
2024-08-18 blackpill board
2024-08-18 Schematic for plackpill
2024-08-22 Add files via upload
    4 Layer board
2024-08-22 Add files via upload
    Files with 10x10 matrix layout (for four layer board)
2024-08-23 Update keyboard.json
    Changed cols/rows pin assignment
2024-08-23 Update keymap.c
    Corrected for missing key
    [keymap.c]
2024-08-25 Add files via upload
    update pcb
2024-08-25 Delete blackpill_version/images/schematic_10x10_matrix.png
    updated...
2024-08-25 Delete blackpill_version/images/schematic_411.png
    updated again
2024-09-11 Update keymap.c
    Some fixes after building prototype
    [keymap.c]
2024-11-02 Update keyboard.json
    changed pid
2024-11-04 Add files via upload
    Current attempts

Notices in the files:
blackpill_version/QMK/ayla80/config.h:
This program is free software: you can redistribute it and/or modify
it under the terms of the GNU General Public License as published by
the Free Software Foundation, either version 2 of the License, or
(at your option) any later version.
